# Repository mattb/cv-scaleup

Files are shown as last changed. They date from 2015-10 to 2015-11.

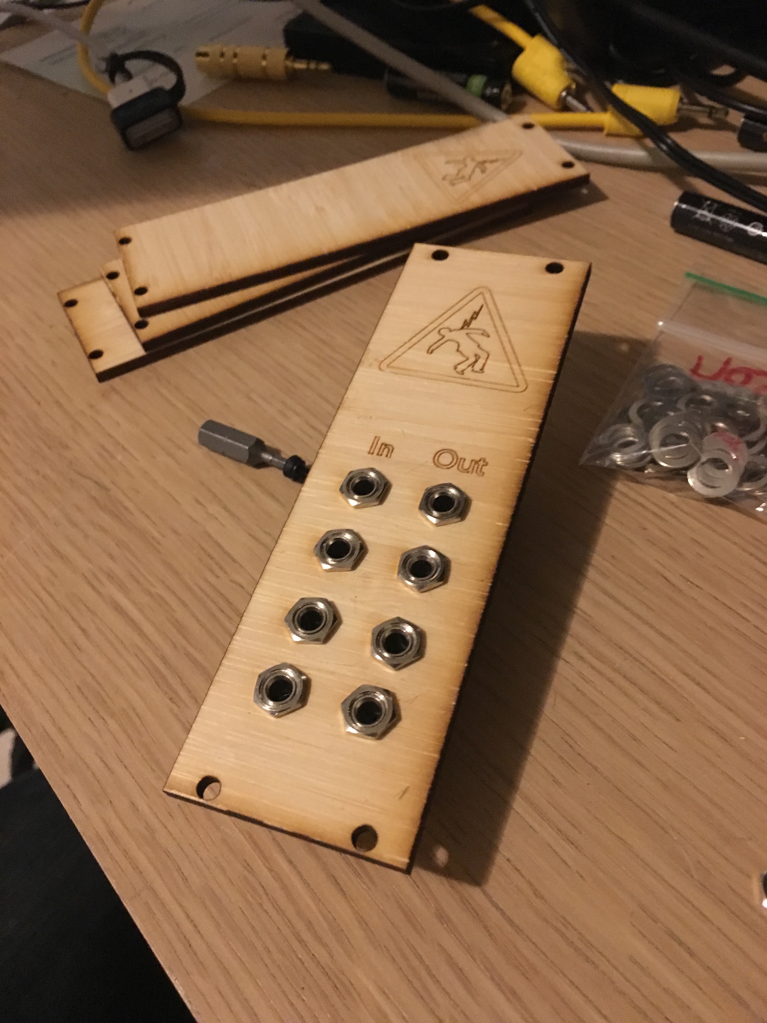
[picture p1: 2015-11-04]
panel-assembled.jpg

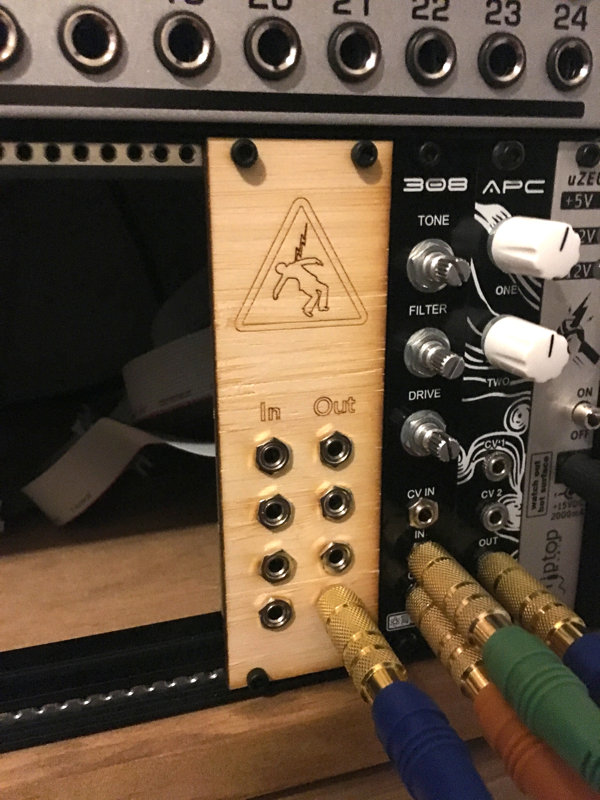
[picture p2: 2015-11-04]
panel-in-rack.jpg

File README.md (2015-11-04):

# Control voltage step-up module

DC-coupled audio interfaces, such as the [MOTU 828 MkI](http://www.soundonsound.com/sos/jul01/articles/motu828.asp)
that I own, are capable
of [outputting voltages](http://www.expert-sleepers.co.uk/siwacompatibility.html) that can
control audio hardware such as
[Eurorack](http://electronicmusic.wikia.com/wiki/Eurorack) modules. However,
most Eurorack modules expect a CV range of -5v to 5v. I measured the MOTU as
outputting -2.88v to 2.88v.

This project contains Eagle files for a Eurorack-mountable opamp circuit with a gain that will
scale four MOTU outputs to the full CV range. It uses a single TL074 quad
op-amp and a few resistors. Calculations for the resistors were made using the calculator at 
http://earmark.net/gesr/opamp/gain_offset.htm

There is also a rudimentary 8HP front panel design in an Illustrator template.

On October 13th 2015, PCBs were ordered from OSHPark and panels from
Ponoko.  A single channel has been successfully tested on a
breadboard, and used to correctly track over 8 octaves of pitch control on
an Arturia Microbrute using Silent Way's Voice Controller plugin in Ableton Live.

On October 27th 2015, the PCBs arrived and the first one was assembled. All four channels worked correctly.

![Assembled board]
(assembled-board.jpg)

![Assembled panel]
(panel-assembled.jpg)

![Completed product in rack]
(panel-in-rack.jpg)

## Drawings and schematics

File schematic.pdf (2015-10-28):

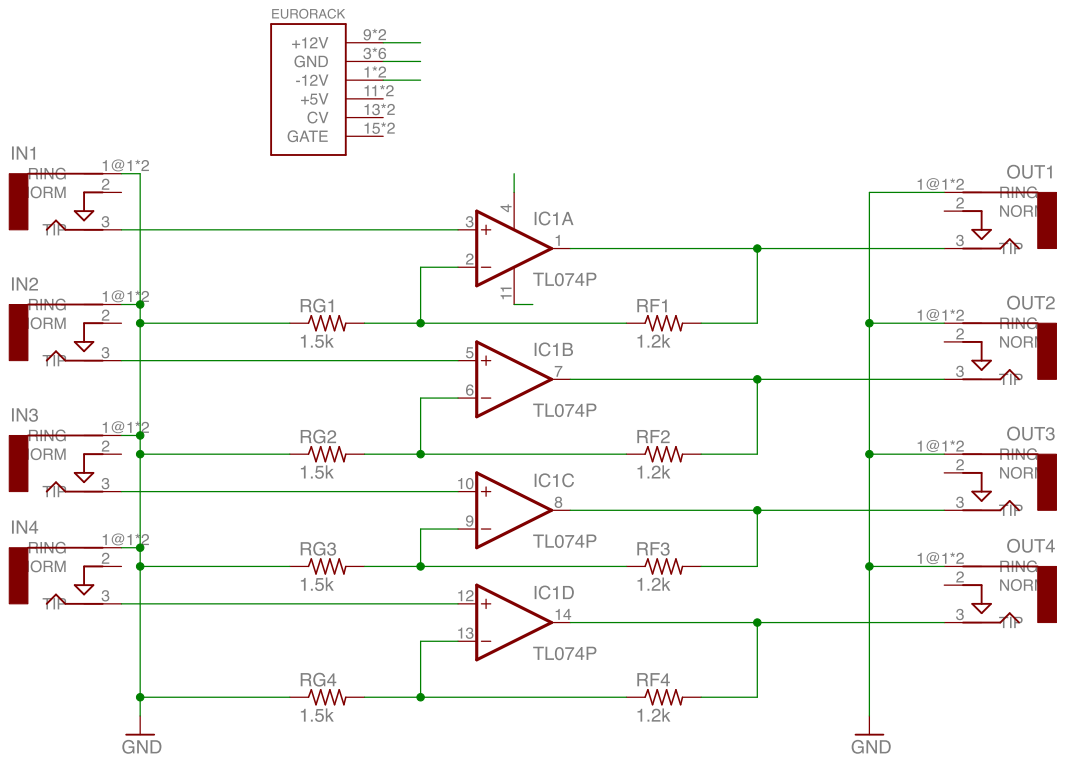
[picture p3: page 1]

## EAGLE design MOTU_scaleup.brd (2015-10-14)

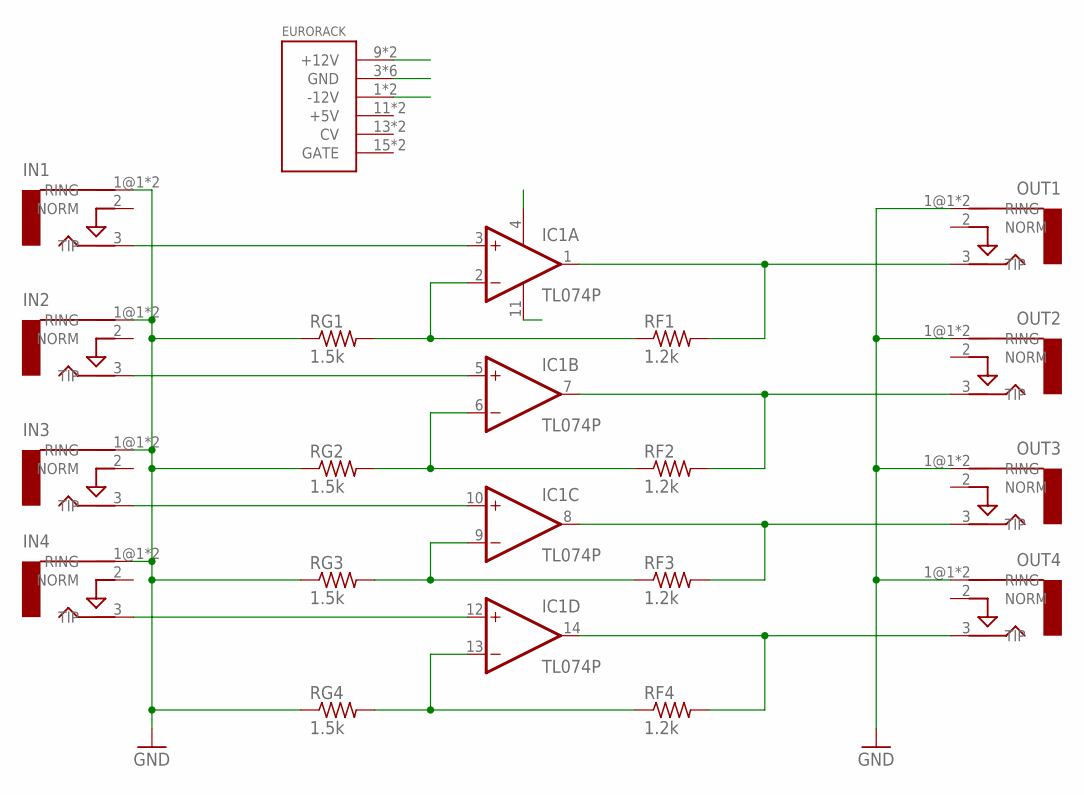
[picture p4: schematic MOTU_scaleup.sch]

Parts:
EURORACK: POWER; POWER_16
IC1: TL074P; DIL14
IN1, IN2, IN3, IN4: AUDIO-JACKERTHENVAR; ERTHENVAR-JACK
OUT1, OUT2, OUT3, OUT4: AUDIO-JACKERTHENVAR; ERTHENVAR-JACK
RF1, RF2, RF3, RF4: 1.2k; 0207/10
RG1, RG2, RG3, RG4: 1.5k; 0207/10

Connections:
+12V: EURORACK.9 (+12V), EURORACK.10 (+12V), IC1.4 (V+)
-12V: EURORACK.1 (-12V), EURORACK.2 (-12V), IC1.11 (V-)
GND: EURORACK.3 (GND), EURORACK.4 (GND), EURORACK.5 (GND), EURORACK.6 (GND), EURORACK.7 (GND), EURORACK.8 (GND), IN1.1@1 (RING), IN1.1@2 (RING), IN2.1@1 (RING), IN2.1@2 (RING), IN3.1@1 (RING), IN3.1@2 (RING), IN4.1@1 (RING), IN4.1@2 (RING), OUT1.1@1 (RING), OUT1.1@2 (RING), OUT2.1@1 (RING), OUT2.1@2 (RING), OUT3.1@1 (RING), OUT3.1@2 (RING), OUT4.1@1 (RING), OUT4.1@2 (RING), RG1.1, RG2.1, RG3.1, RG4.1
unnamed: IC1.3 (+IN), IN1.3 (TIP)
unnamed: IC1.5 (+IN), IN2.3 (TIP)
unnamed: IC1.10 (+IN), IN3.3 (TIP)
unnamed: IC1.12 (+IN), IN4.3 (TIP)
unnamed: IC1.14 (OUT), OUT4.3 (TIP), RF4.2
unnamed: IC1.8 (OUT), OUT3.3 (TIP), RF3.2
unnamed: IC1.7 (OUT), OUT2.3 (TIP), RF2.2
unnamed: IC1.1 (OUT), OUT1.3 (TIP), RF1.2
unnamed: IC1.6 (-IN), RF2.1, RG2.2
unnamed: IC1.9 (-IN), RF3.1, RG3.2
unnamed: IC1.13 (-IN), RF4.1, RG4.2
NNN: IC1.2 (-IN), RF1.1, RG1.2

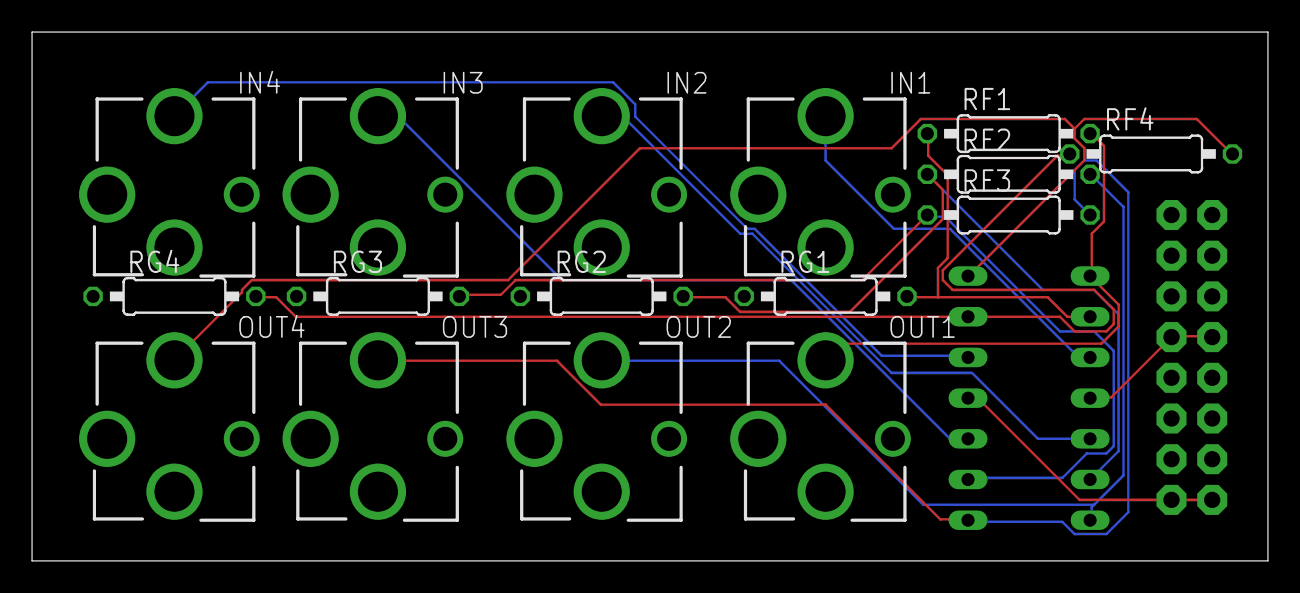
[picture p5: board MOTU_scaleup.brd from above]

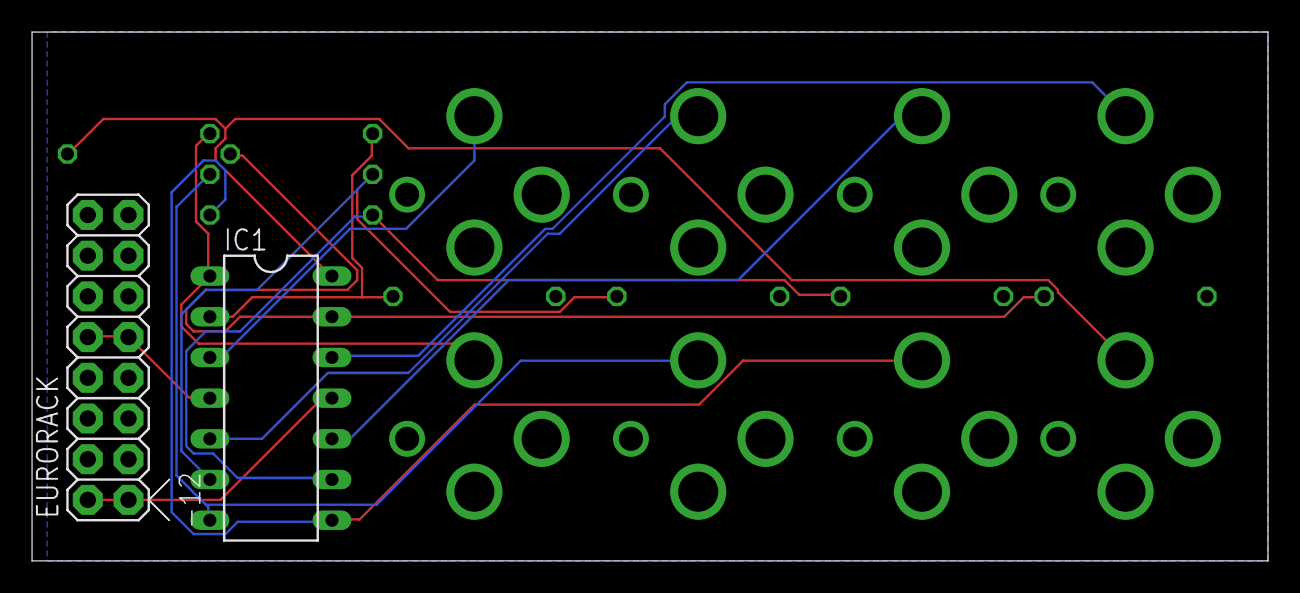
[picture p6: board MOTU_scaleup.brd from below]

Board: 2 copper layers, 77.1 x 33.0 mm, 18 parts (2 on the bottom side), 15 nets.

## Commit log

2015-10-28 Assembly updates.
2015-11-04 Final assembly pics
